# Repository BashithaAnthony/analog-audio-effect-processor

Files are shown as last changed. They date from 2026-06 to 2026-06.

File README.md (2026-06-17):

# Analog Audio Effect Processor

## Overview

Fully analog audio processing unit incorporating multiple audio effects, equalization stages, and dedicated power supply circuitry for audio signal enhancement.

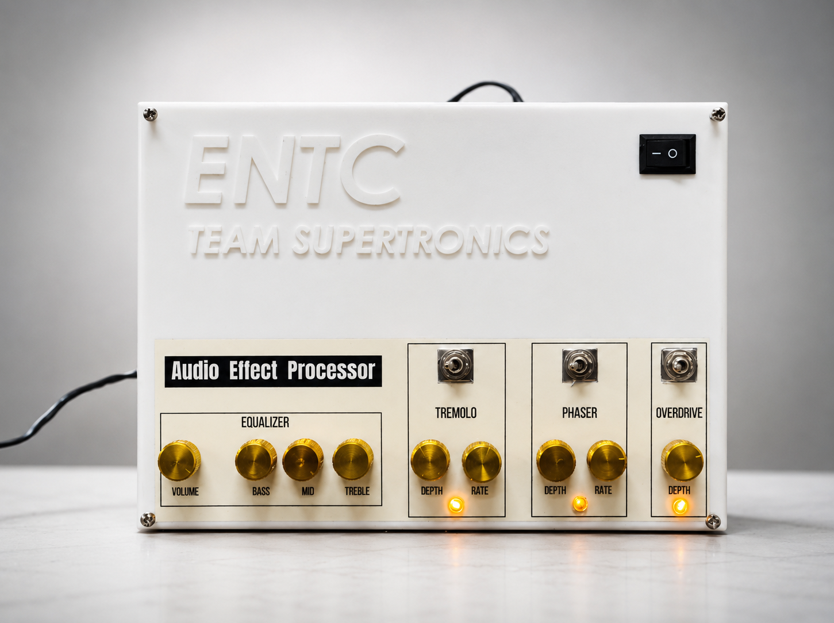
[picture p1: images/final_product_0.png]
Product Overview


## Features

* Equalizer section
* Tremolo effect
* Phaser effect
* Overdrive effect
* Analog signal processing
* Dedicated regulated power supply

## Technologies

* Analog Electronics
* LTSpice
* Altium Designer
* SolidWorks

## My Contributions

* Designed and simulated overdrive/distortion unit, input and output buffer circuits
* Developed the PCB using Altium
* Performed circuit analysis and validation
* Integrated multiple effect stages into a single system
* Designed initial sketches of enclosure and assisted in dinal enclosure designing

## Project Status

Completed

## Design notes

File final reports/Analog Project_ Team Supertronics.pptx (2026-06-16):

## EN2091 Analog Project

Team Supertronics

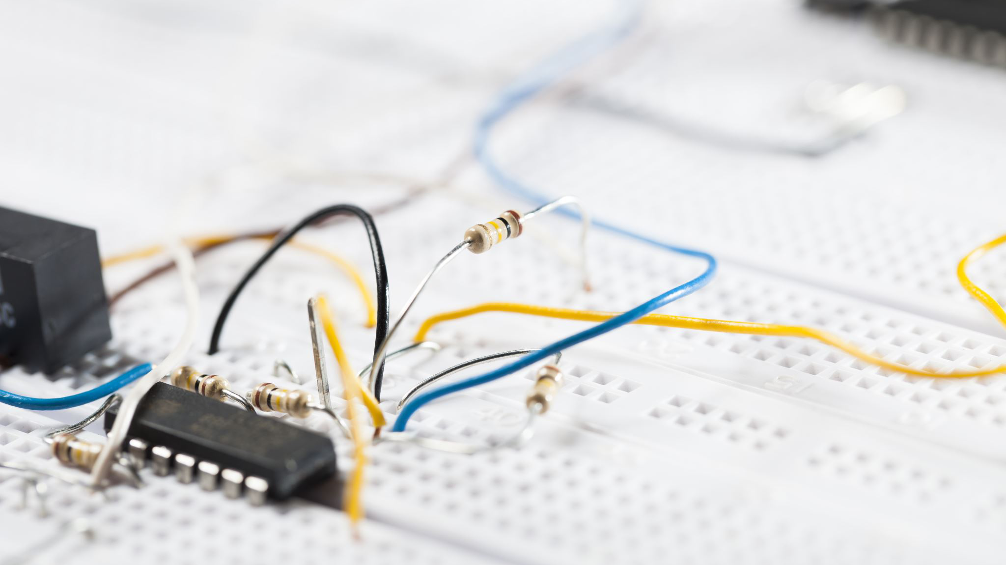
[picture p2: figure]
Electronics protoboard

230045X

230140J

230477X

230730T

Anthony C.S.B.

Dharmakeerthi P.K.G.C.L.

Perera H.A.J.I.

Wijethilaka J.S.

## Analog Audio Effect Processor

## Block Diagram

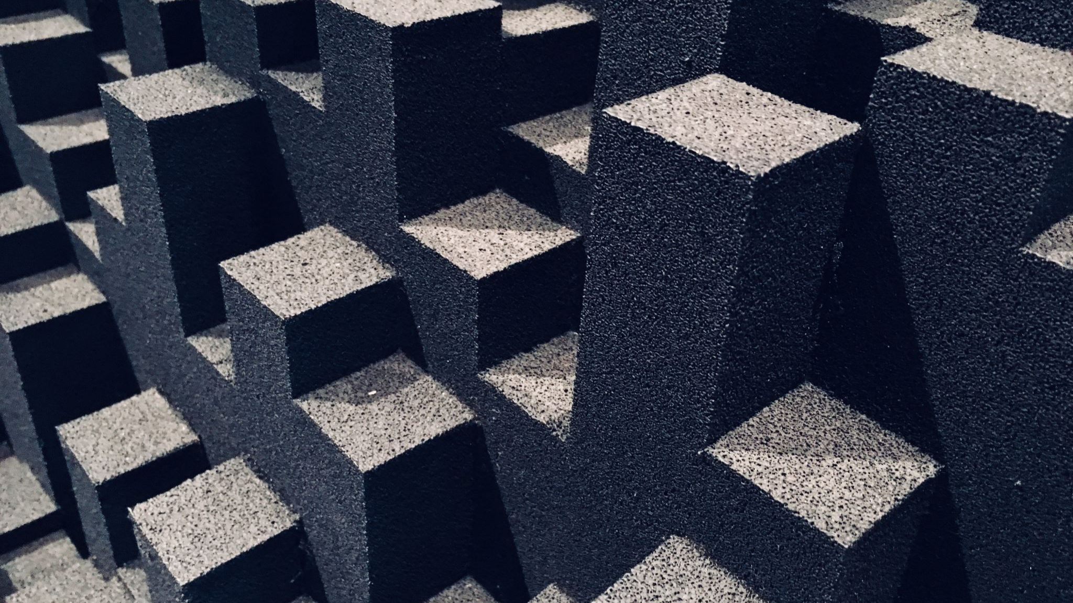
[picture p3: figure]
3D square and rectangle

Input Buffer

Equalizer

Tremolo

Overdrive

Phaser

Output Buffer

Regulated 12V Power Supply

## Power Supply

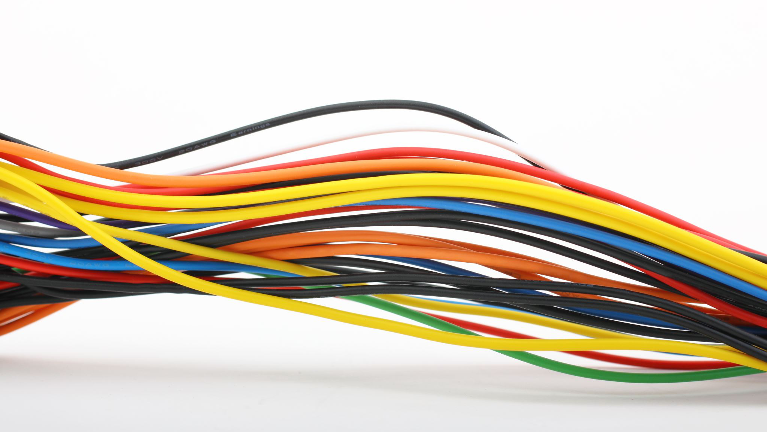
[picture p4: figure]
Colorful wires
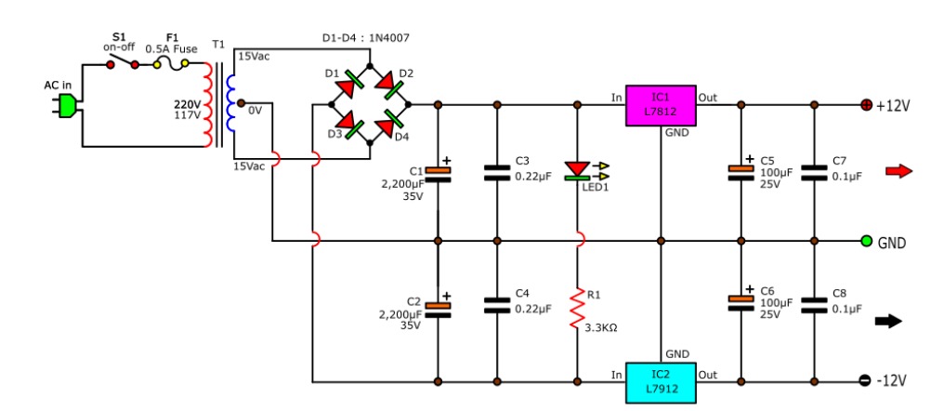
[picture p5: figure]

## 3-Band Audio Equalizer

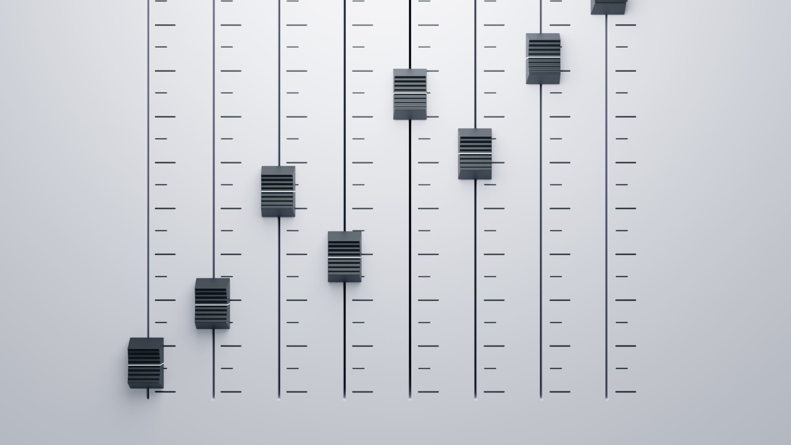
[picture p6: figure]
Volume sliders

## 3-Band Audio Equalizer

Introduction
- 3-band equalizer is an audio processing tool used to adjust the amplitude of different frequency bands in a sound signal.
- Commonly used in audio systems, music production, and live sound to shape the tonal quality of audio.
Functionality
- Allows boosting or cutting each frequency band independently and helps in improving clarity, warmth, and overall balance of audio.

## PCB Schematic (Audio Eq)

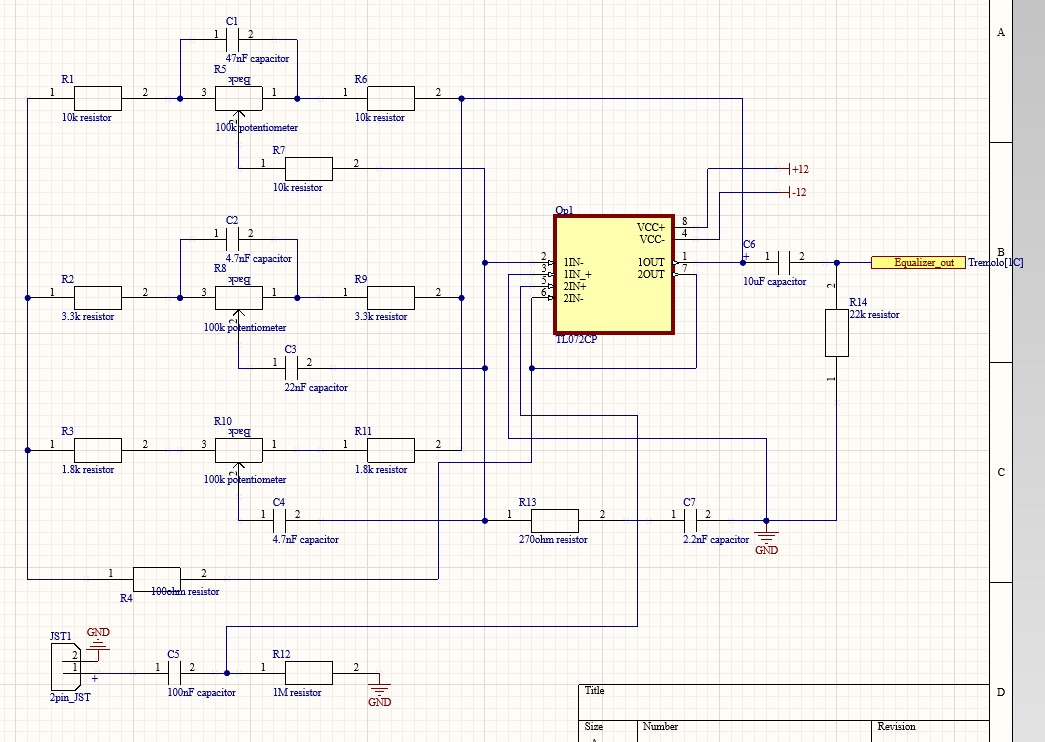
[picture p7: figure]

## Overdrive Module

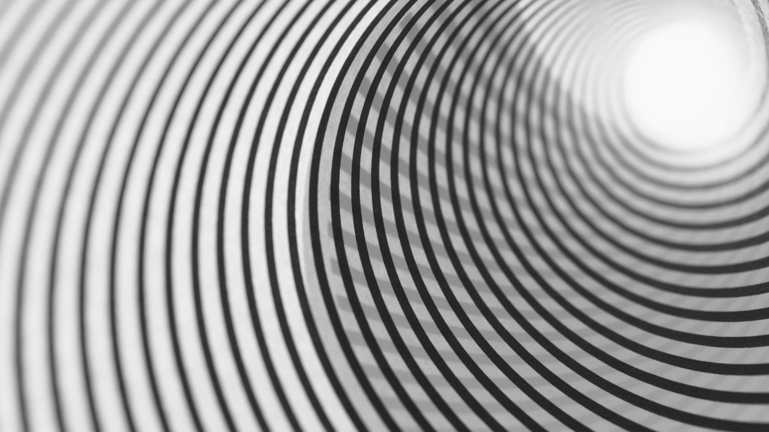
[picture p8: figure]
An illusion of swirling lines in black and white

## Overdrive Module

Introduction
- An Overdrive module is an audio effects unit that intentionally distorts the audio signal to produce a warm, saturated sound.
- Commonly used in electric guitars, synthesizers, and audio processing to add harmonic richness and character.
Functionality
- Boosts the signal and introduces harmonic distortion, making the sound more driven.
- Includes controls for Gain ( amount of distortion) and Volume (output signal strength ).

## PCB Schematic (Overdrive Module)

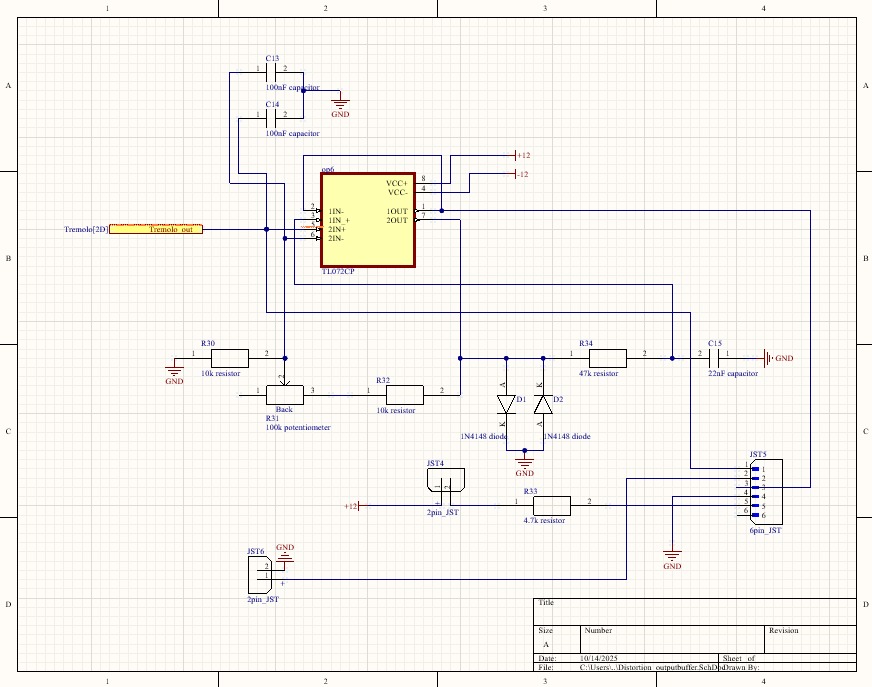
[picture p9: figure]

## Tremolo Module

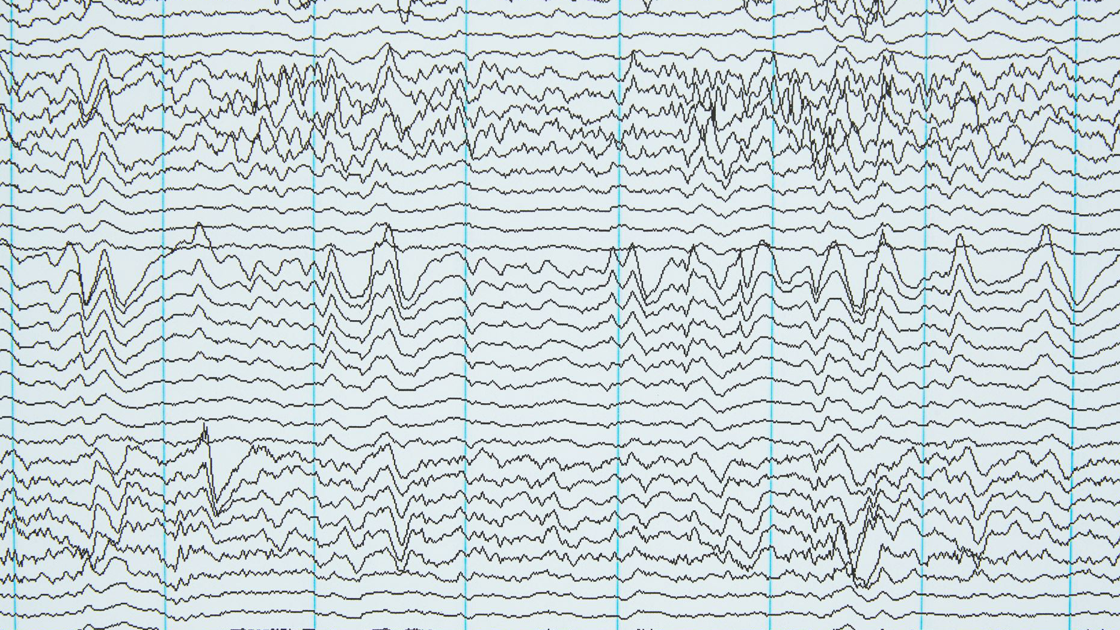
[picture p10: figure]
Zigzag indicator line

## Tremolo Module

Introduction
- A Tremolo module is an audio effect that modulates the amplitude (volume) of an audio signal periodically.
Functionality
- Modulates the amplitude of the input signal.
- Includes controls for Rate (speed of modulation) and Depth (intensity of the effect)

## PCB Schematic (Tremolo Module)

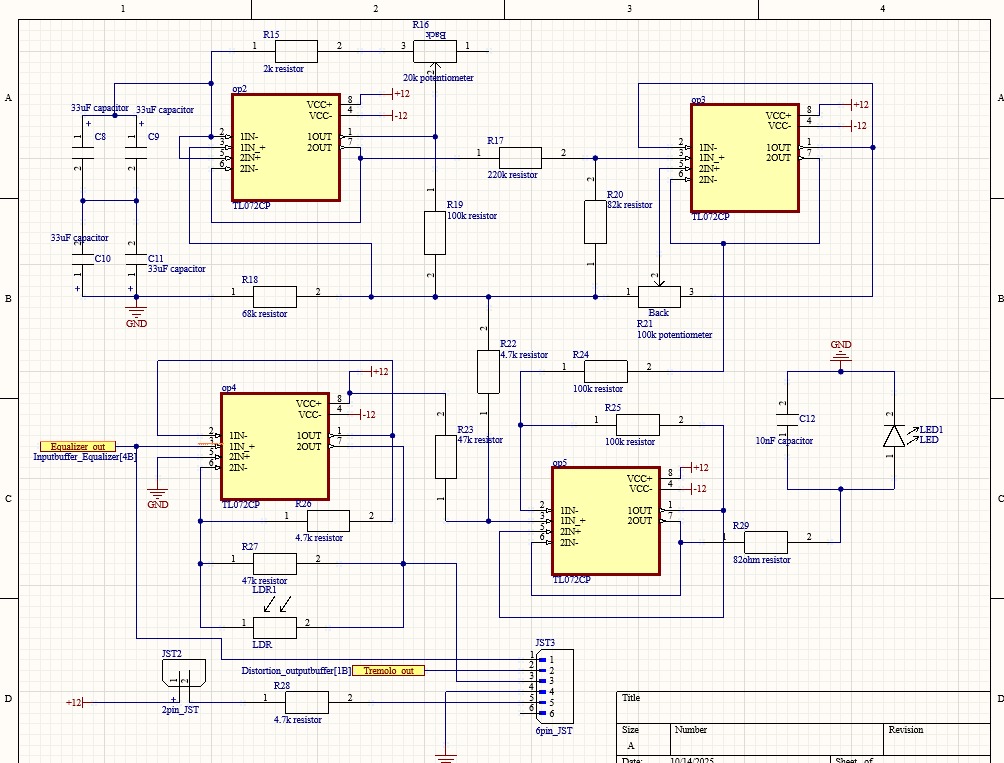
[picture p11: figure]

## Phaser Module

## Phaser Module

Introduction
- A Phaser module is an audio effect that creates sweeping, swirling sounds by splitting the audio signal and shifting the phase of one part before recombining.
Functionality
- Splits the input signal into two paths and shifts the phase of one path.
- Recombines the signals, causing constructive and destructive interference, producing peaks and troughs in the frequency spectrum.
- Includes controls such as Rate (speed of sweep) and Depth (intensity of effect)

## PCB Schematic (Phaser Module)

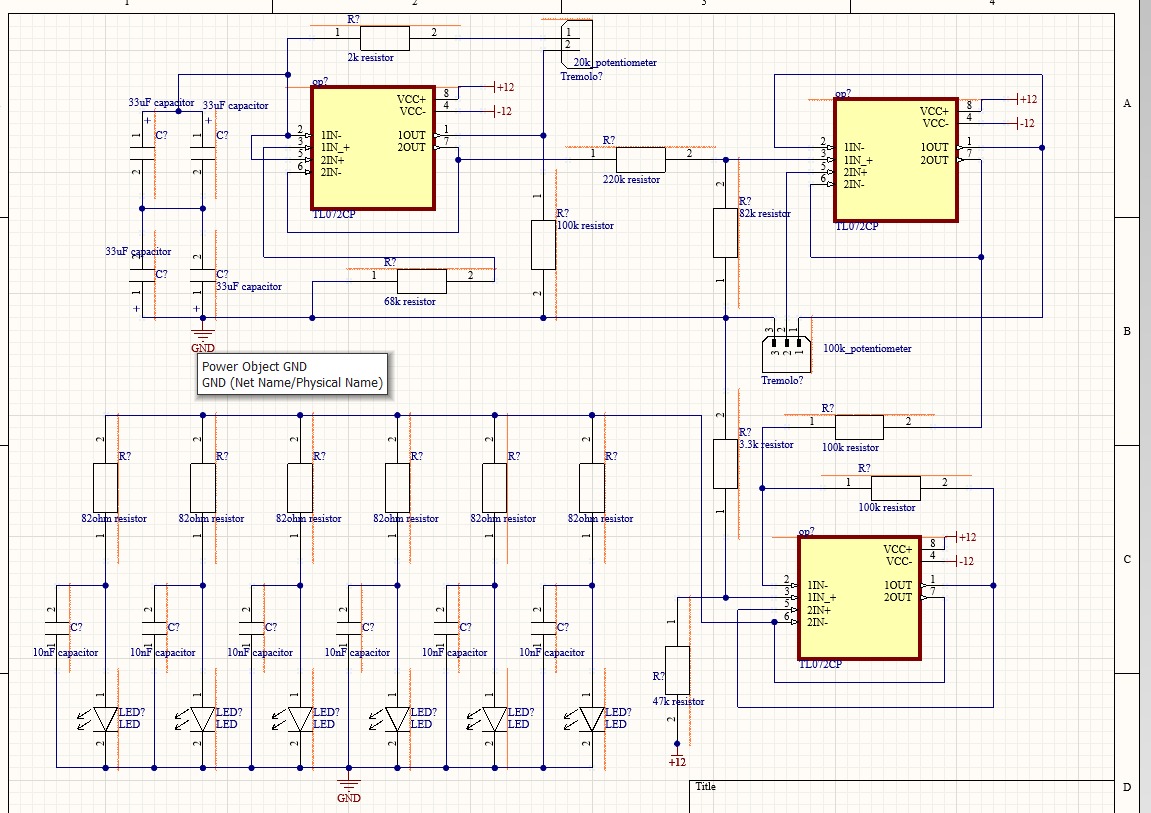
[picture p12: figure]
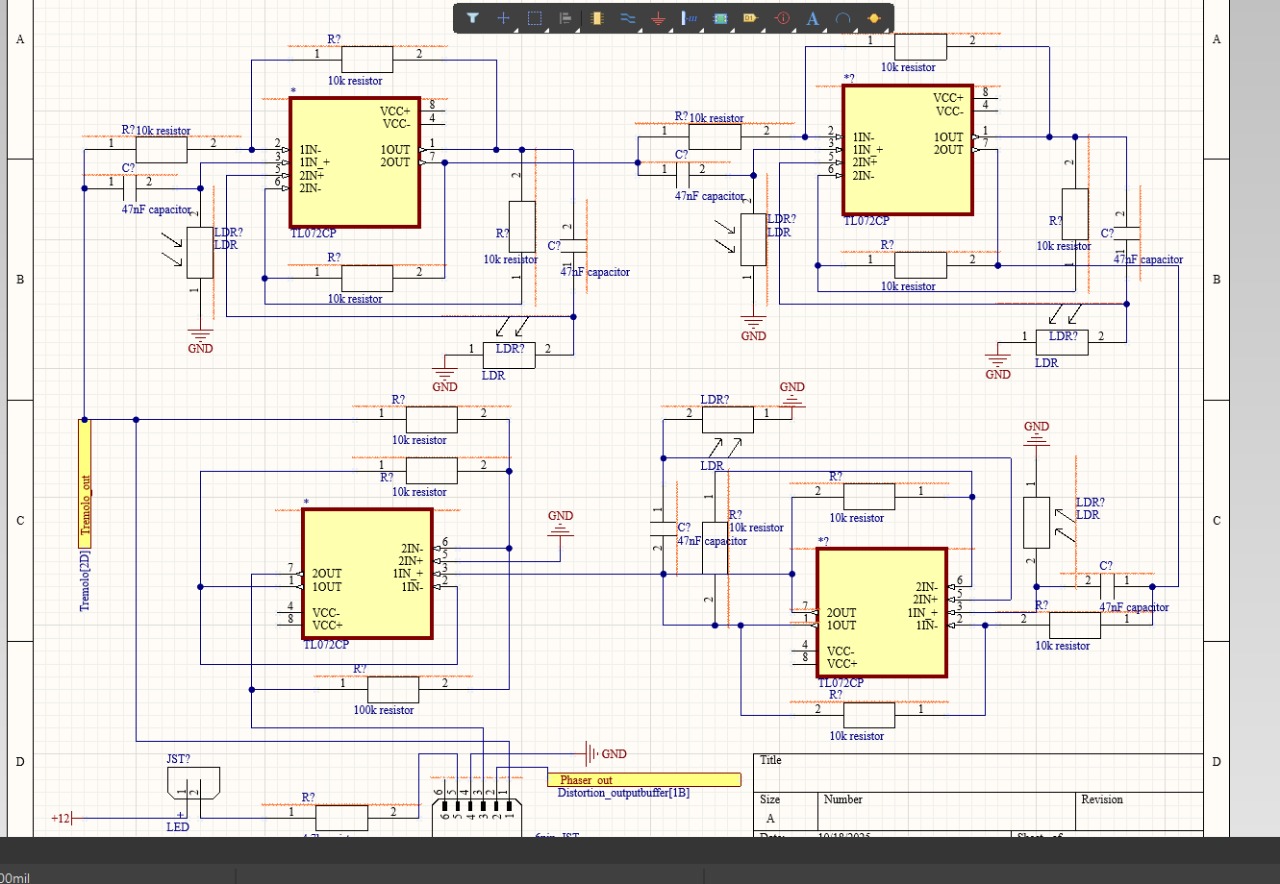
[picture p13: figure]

## PCB Layout

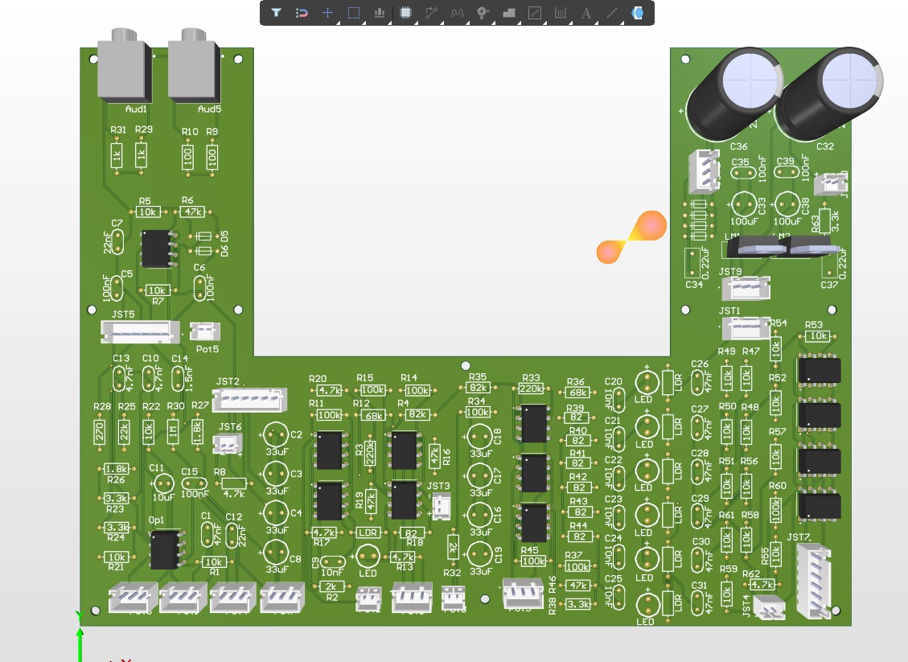
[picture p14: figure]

## Enclosure Design

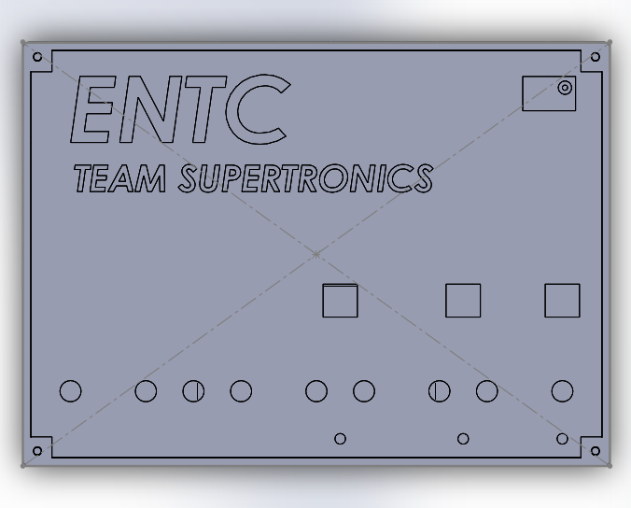
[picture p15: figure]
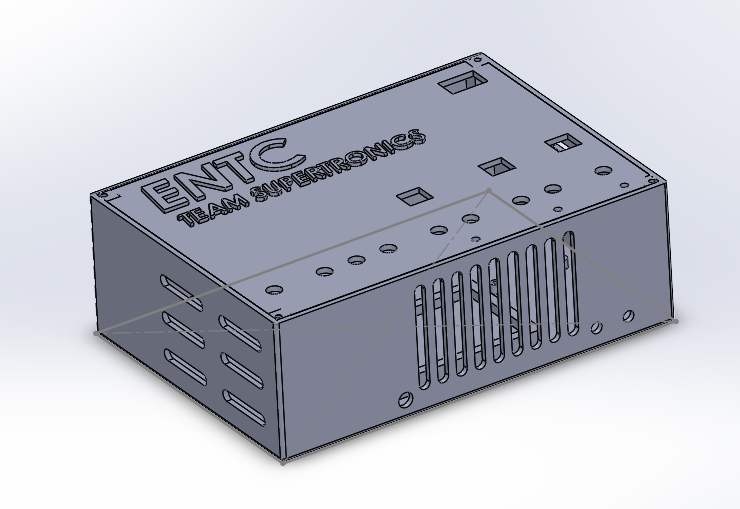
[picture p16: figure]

## Task Allocation

230045X | Overdrive Module, PCB Design
230140J | Phaser Module, Enclosure Design
230477X | Tremolo Module, Component Selection, Assembling
230730T | Audio Equalizer, Power Supply

## Thank You

Team SuperTronics

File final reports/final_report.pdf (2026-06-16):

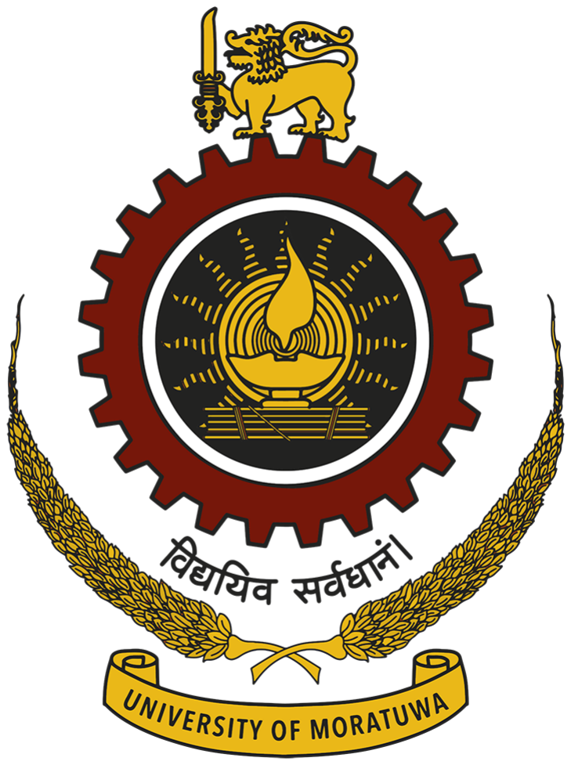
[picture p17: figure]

Department of Electronic & Telecommunication Engineering University of Moratuwa
Sri Lanka.

# Analog Audio Effects Processor

Group Name : Team SuperTronics

Group Members :

230045X | Anthony C.S.B
230140J | Dharmakeerthi P.K.G.C.L
230477X | Perera H.A.J.I
230730T | Wijethilaka J.S.

Submitted in partial fulfillment of the requirements for the module EN 2091 Laboratory Practice and Projects

Date : 14-12-2025

Analog Audio Effects Processor | Group No: 27

Abstract

This project presents the design and implementation of an analog audio effects processor which combines multiple commonly used audio effect into a single modular platform. The modules present in the project includes a power supply module capable of delivering a +-12V dual rail linear power supply, an input buffer, a three band audio equalizer, three audio effects namely as tremolo, phaser and distortion and an output buffer. The dual rail linear power supply is employed to ensure stable and low noise operation of the analog circuitry.

Each functional module is implemented using operational amplifier based circuits with careful attention given to impedance matching, maintaining signal integrity, noise reduction and maintaining proper gain control. Modulation effects such as tremolo and phaser are realized using low frequency oscillators and optical control elements (optocouplers) to achieve smooth and musically present variations. The distortion stage employs diode based clipping to introduce controlled non linearities suitable to achieve the desired effect.

The system was designed simulated and tested using industry standard software. Experimental results demonstrated that the processor successfully produced the intended audio effects while maintaining stable operation and acceptable signal quality. This project provides practical insight into analog audio circuit design and highlights the effectiveness of modular architecture in multi effect systems.

1

## Abbreviations and Acronyms

AC | Alternating Current
DC | Direct Current
LFO | Low Frequency Oscillator
EQ | Equalizer
PCB | Printed Circuit Board
LED | Light Emitting Diode
LDR | Light Dependent Resistor
IC | Integrated Circuit
RC | Resistor–Capacitor
PSU | Power Supply Unit
VCA | Voltage Controlled Amplifier

2

## Contents

1 Introduction and Functionality | 4
2 System Architecture | 4
3 Component Selection | 6
4 PCB Design | 7
5 Enclosure Design | 8
6 Software Simulation and Hardware Testing | 9
7 Conclusion & Future Works | 11
8 Contribution of Group Members | 11

3

## 1 Introduction and Functionality

Audio Effects play a vital role in audio signal processing by modifying the tonal, temporal and harmonic characteristics of the input audio signal. While modern digital signal processing techniques are widely used, analog audio effects remain popular due to their natural sound quality, continuous time operation and musical responce. designing analog audio effects also provides strong strong educational value as it requires a sound understanding of operational amplifiers, passive components and signal conditioning techniques.
The objective of this project is to design and implement an analog audio effects processor capable of processing a audio input signal through several commonly used audio effects. The system is intended to demonstrate practical applications of analog electronics concepts such as amplification, filtering, modulation and non linear signal processing.
The developed system consists of several modular stages each performing a specific function. An input buffer is used to match the impedance between the guitar pickup and the processing circuitry. A three band equalizer provides frequency shaping through bass, mid and treble controls. Modulation based effects such as tremolo and phaser are implemented using LFOs and optical control elements. A distortion stage introduces controlled non linear clipping to produce overdrive effects. Finally an output buffer ensures stable signal delivery to external audio output equipment.
The overall system accepts audio input through a 3.5mm audio input, processes it through the selected effects while preserving signal integrity and produces a clean, low noise audio output.

## 2 System Architecture

The audio effects processor is designed using a modular system architecture where each functional block operates independently while remaining electrically compatible with the rest of the system. This approach simplifies design, testing, debugging and future expansion. The system is powered by a centralized dual rail power supply that provides ±12 V to all analog stages.
The signal flow begins at the audio input jack where the incoming audio signal is first passed through an input buffer. This buffer provides high input impedance and prevents signal loading. The buffered signal is then routed through the equalizer stage, allowing tonal adjustment before modulation effects are applied. The processed signal subsequently passes through the tremolo and phaser stages where time varying modulation effects are introduced. A distortion stage follows, adding harmonic content through diode-based clipping. Finally, an output buffer delivers the processed signal to the output jack with low output impedance.
Careful attention has been given to inter module interfacing. AC coupling capacitors are used between stages to block DC offsets, while buffer amplifiers prevent impedance mismatches. Local decoupling capacitors are placed near op-amp power pins to minimize noise and ensure stable

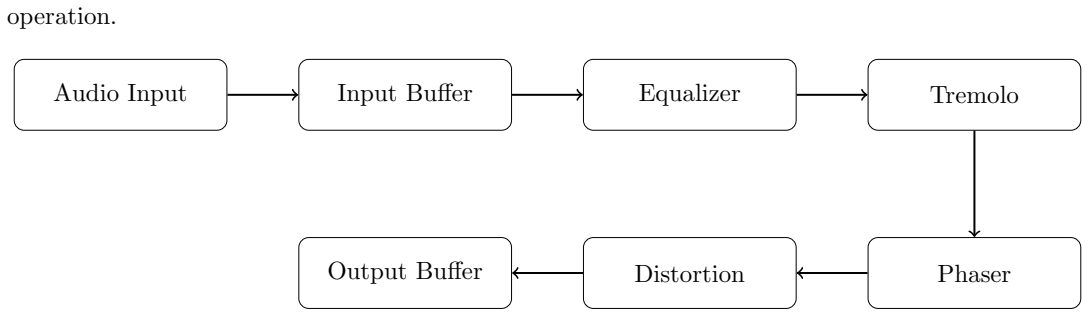
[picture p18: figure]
operation.; Audio Input; Input Buffer; Equalizer; Tremolo; Output Buffer; Distortion; Phaser

Figure 1: System architecture of the analog multi-effects audio processor

4

### 2.1 Table and Figure

Figures and tables are used in this report to clearly illustrate the structure and functionality of the proposed analog audio effects processor. Figure 1 presents the overall block diagram of the system, highlighting the modular signal flow from the audio input stage to the output buffer. The diagram demonstrates the sequential arrangement of the input buffer, equalizer, modulation effects, distortion stage and output buffer.
Table 1 summarizes the main functional modules of the system along with their respective functions and key components used in each module. The table provides a concise overview of the system organization and aids in understanding the role of each block within the complete audio processing chain.

Table 1: Functional modules of the audio effects processor

Module | Function | Key Components
Input Buffer | Impedance matching | TL072 op-amp
Equalizer | Frequency shaping | Op-amps, RC networks
Tremolo | Amplitude modulation | LFO, LED–LDR
Phaser | Phase modulation | LFO, LED–LDR
Distortion | Non-linear clipping | Diodes, op-amp
Output Buffer | Signal driving | TL072 op-amp

### 2.2 Equations

The operation of the proposed analog audio effects processor can be explained using a set of fundamental equations related to amplification, filtering and modulation. These equations describe the behavior of key circuit blocks implemented in the system.
The voltage gain of the operational amplifier stages used in the input buffer, equalizer, distortion and output buffer modules is determined using the standard non-inverting amplifier gain expression given by

Av = 1 +

Rf

Rin

, | (1)

where Rf represents the feedback resistance and Rin denotes the input resistance.

Frequency-selective behavior in the equalizer and filtering stages is characterized by the RC cutoff frequency, which is given by

fc =

1
2πRC , | (2)

where R and C are the resistance and capacitance values of the respective filter network.

The tremolo effect is based on the principle of amplitude modulation, in which the amplitude of the audio signal is varied by a low-frequency control signal. This behavior can be represented as

y(t) = x(t) [1 + m sin(2πfLF Ot)], | (3)

where x(t) is the input audio signal, m is the modulation depth, and fLF O is the frequency of the low frequency oscillator.

All equations are used to guide the design and analysis of the corresponding circuit blocks and support the functional behavior of the implemented audio effects.

5

### 2.3 Guidelines for References

The reference list is included in the References section at the end of this document. Sources are cited within the text using numbered references enclosed in square brackets. Each reference number corresponds to an entry in the reference list and appears in the order of first citation.
The references used in this project include textbooks on analog electronics and audio circuit design, as well as manufacturer datasheets for the components employed in the system.

## 3 Component Selection

Component selection was carried out with careful consideration of audio performance, reliability, availability, and suitability for analog signal processing. The selected components ensure stable operation, low noise, and effective realization of the intended audio effects.

- Operational Amplifier (TL072): The TL072 operational amplifier was chosen for the majority of signal processing stages including the input buffer, equalizer, distortion, tremolo, phaser and output buffer. This device features low input noise, JFET input transistors providing high input impedance and a wide bandwidth with a high slew rate suitable for audio based applications. The dual op-amp configuration also reduces component count and simplifies circuit implementation.
- Voltage Regulators (LM7812 and LM7912): The dual-rail power supply was implemented using LM7812 and LM7912 voltage regulators to provide regulated ±12 V DC outputs. These linear regulators were selected due to their reliability and low output ripple, which are important characteristics for analog audio circuits.
- Rectification and Filtering Components: Bridge rectification was achieved using 1N4007 diodes, selected for their high reverse voltage rating and suitability for low frequency rectification. Electrolytic capacitors were used for bulk smoothing of the rectified voltage, while ceramic capacitors were employed for high-frequency decoupling to improve power supply stability.
- Resistors and Capacitors: Resistors and capacitors were selected to form gain-setting, biasing, and frequency selective networks throughout the system. RC networks were designed to operate within the audible frequency range and to ensure stable and predictable circuit behavior.
- Potentiometers: Potentiometers were incorporated in the equalizer, tremolo, phaser and distortion stages to provide user adjustable control over gain, frequency, modulation rate and modulation depth. These components were selected to allow precise adjustment of circuit parameters ensuring that the required frequency response and gain characteristics could be achieved under varying operating conditions.
- Optical Components (LEDs and LDRs): Light-emitting diodes (LEDs) and light-dependent resistors (LDRs) were used in the tremolo and phaser modules to implement optical modulation. This approach helps achieve simple and smooth modulation of the audio signal.
- Diodes for Distortion (1N4148): Silicon signal diodes (1N4148) were employed in the distortion stage to introduce controlled non linear clipping. These diodes were selected due to their fast switching characteristics and consistent forward voltage which enable predictable and repeatable distortion behavior suitable for audio applications.

6

## 4 PCB Design

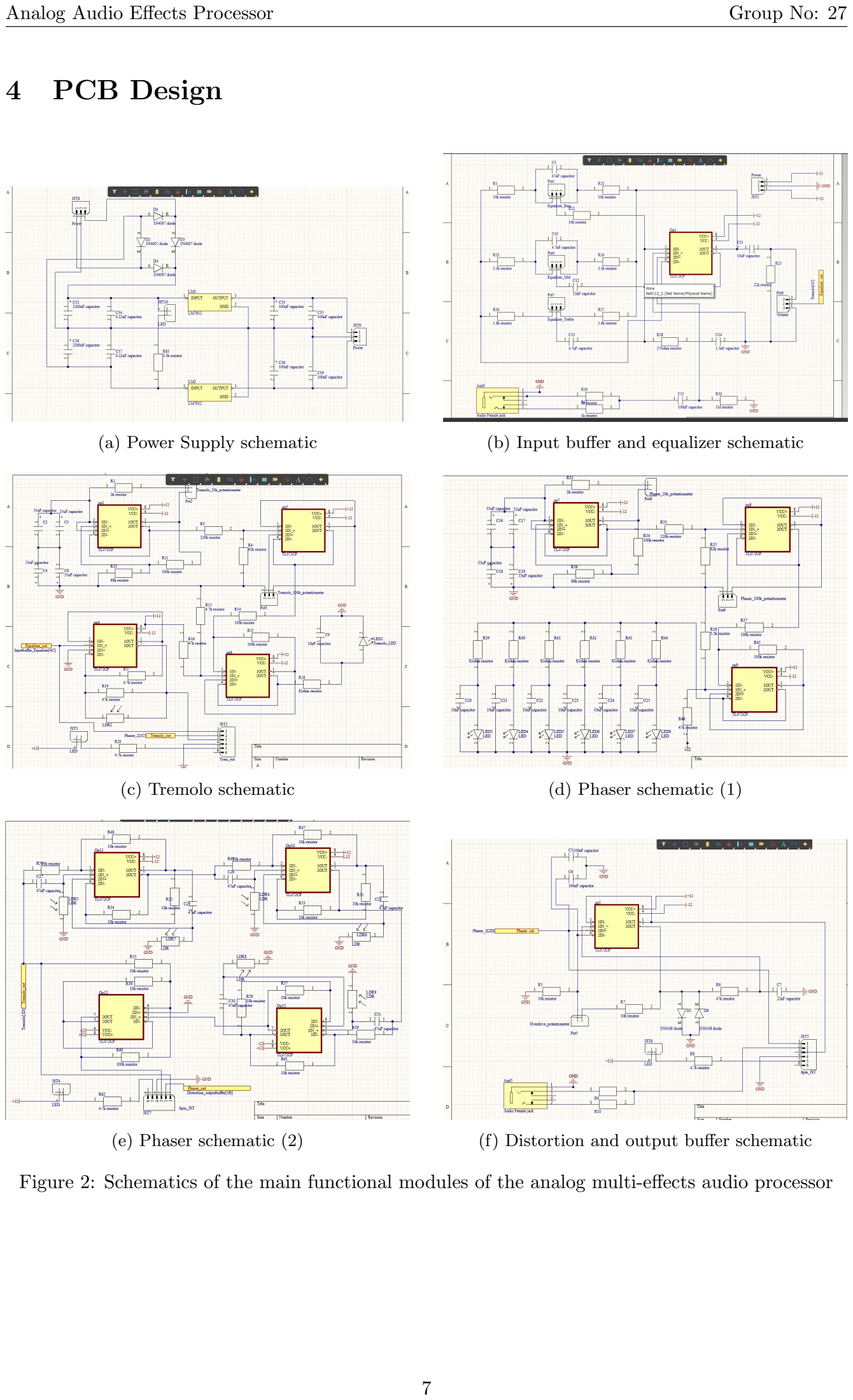
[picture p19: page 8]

(a) Power Supply schematic | (b) Input buffer and equalizer schematic
(c) Tremolo schematic | (d) Phaser schematic (1)
(e) Phaser schematic (2) | (f) Distortion and output buffer schematic

Figure 2: Schematics of the main functional modules of the analog multi-effects audio processor

7

## 5 Enclosure Design

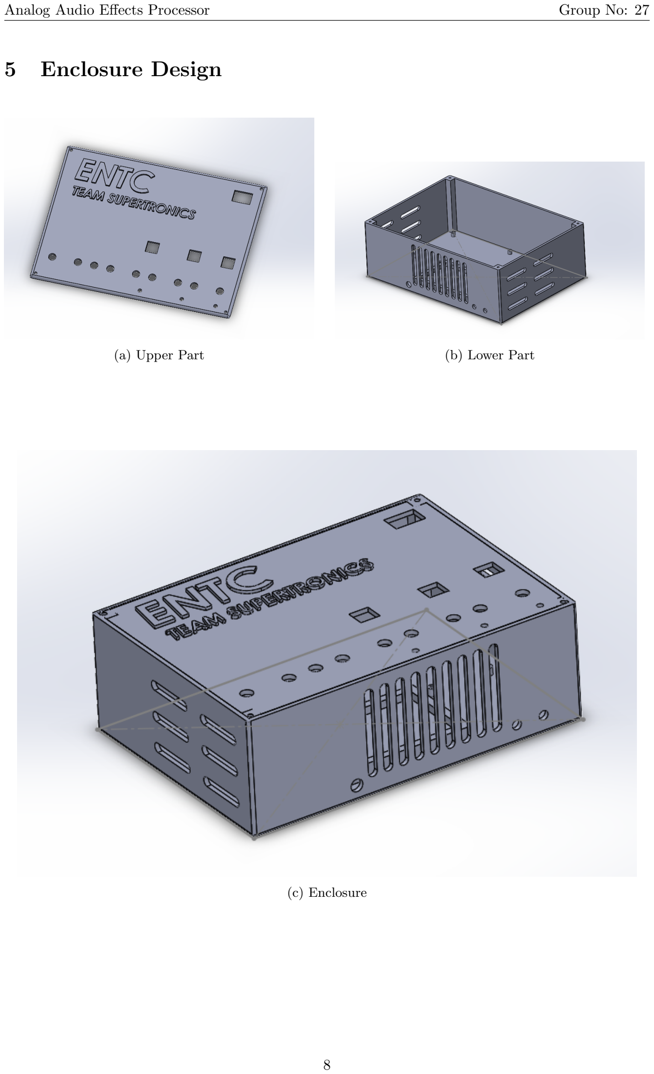
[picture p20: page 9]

(a) Upper Part | (b) Lower Part
(c) Enclosure

8

## 6 Software Simulation and Hardware Testing

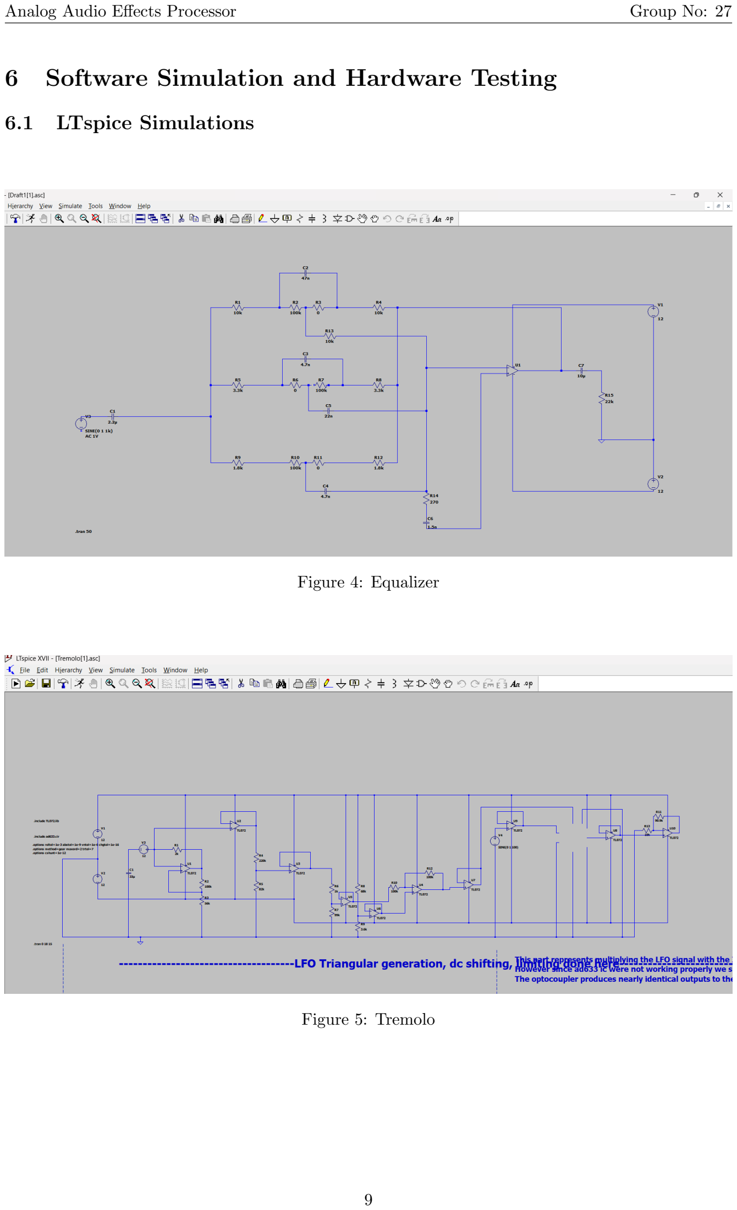
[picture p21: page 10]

### 6.1 LTspice Simulations

Figure 4: Equalizer

Figure 5: Tremolo

9

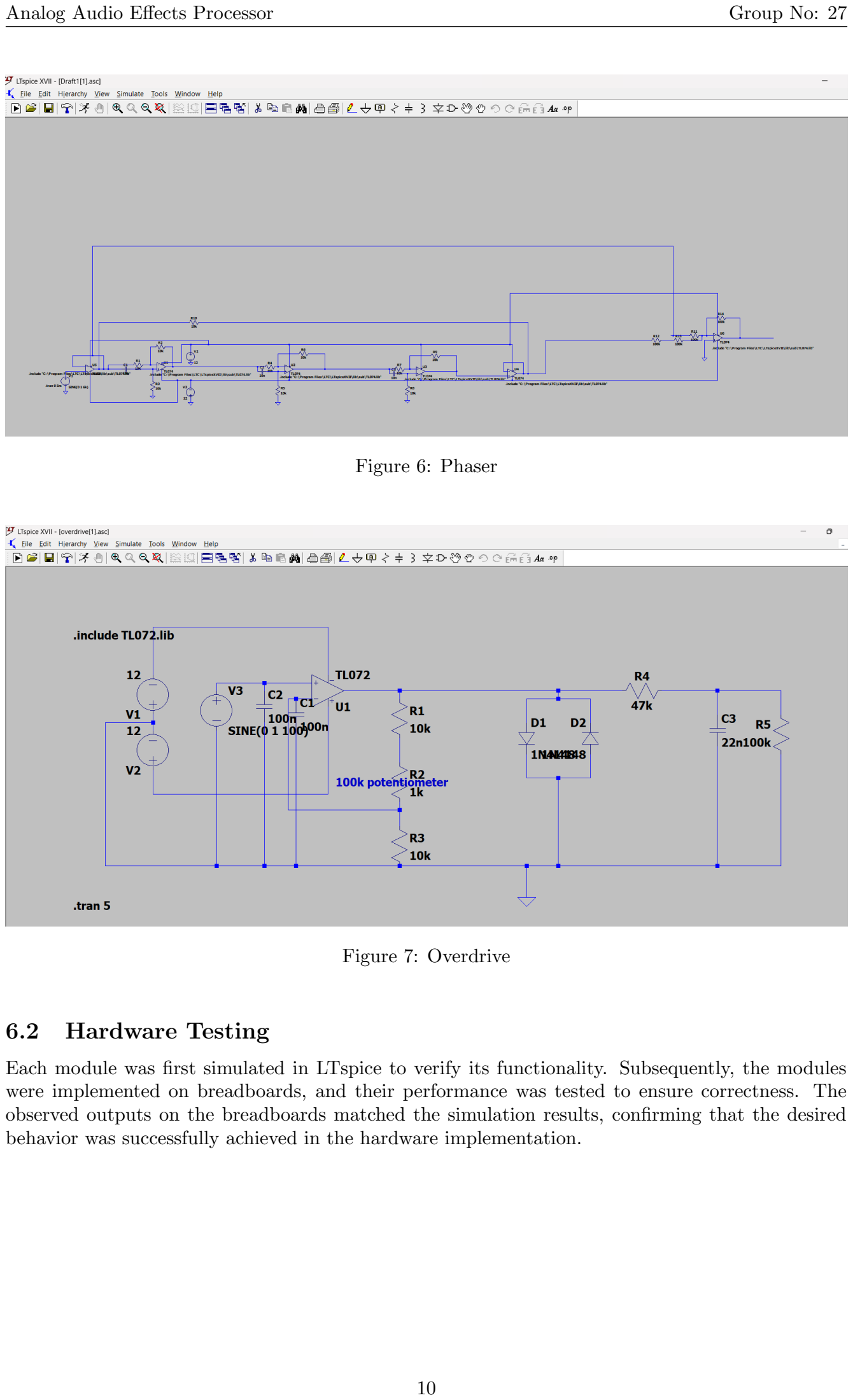
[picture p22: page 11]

Figure 6: Phaser

Figure 7: Overdrive

### 6.2 Hardware Testing

Each module was first simulated in LTspice to verify its functionality. Subsequently, the modules were implemented on breadboards, and their performance was tested to ensure correctness. The observed outputs on the breadboards matched the simulation results, confirming that the desired behavior was successfully achieved in the hardware implementation.

10

## 7 Conclusion & Future Works

We successfully achieved the design and implementation of an analog audio effects processor intended for audio signal processing. The system integrates several commonly used audio effects including a three band equalizer, tremolo, phaser and distortion into a single modular platform powered by a dual-rail ±12 V supply. The modular architecture adopted in the design facilitated systematic development, testing, and integration of individual functional blocks.
Hardware testing confirmed stable operation of the power supply and reliable performance of all signal processing stages. Each effect module produced the intended audible characteristics while proper buffering and grounding ensured acceptable signal quality with acceptable noise. Through this project we gained valuable practical experience in operational amplifier based circuit design, analog signal processing, PCB layout considerations and system level integration of multiple electronic subsystems.
Several enhancements can be considered as future work to further improve the functionality and performance of the system. Digital control of effect parameters using a microcontroller could be introduced to enable preset storage and improved user interaction. Additional audio effects such as delay, chorus and reverb could be incorporated to expand the versatility of the processor.

## 8 Contribution of Group Members

Index | Tasks
230045X | Overdrive Module, PCB Design
230140J | Phaser Module, Enclosure Design
230477X | Tremolo Module, Component Selection, Assembling
230730T | Audio Equalizer, Power Supply

## Appendix

## References

[1] B. Cordell, Designing Audio Circuits and Systems, Taylor & Francis Ltd, 2024.
[2] J. C. M. Lam, Analog Audio Amplifier Design, Focal Press, 2024.

11

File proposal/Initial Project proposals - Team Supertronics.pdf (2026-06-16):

# Feasibility Report

## Analog Audio E!ect Processor

Group Members:
230045X, 230140J, 230477X, 230730T

## Functionality

The proposed Analog Audio E!ect Processor is a modular, fully analog device designed to apply multiple sound e!ects to an audio signal in real time. The system will feature four distinct audio e!ects as follows:

- Overdrive/Distortion – Adds harmonic saturation and controlled clipping for a warm or aggressive tone.
- Phaser – Produces sweeping, phase-shifted comb filter e!ects using multiple all-pass filter stages.
- Tremolo – Modulates the amplitude of the signal periodically for a pulsing e!ect.
- Spring Reverb – Simulates reverberation using a mechanical spring tank.

Each module will be independently switchable, allowing the user to activate any combination of e!ects as the user wants. The signal will be processed in series for a straightforward and compact design.

## Block Diagram of the System

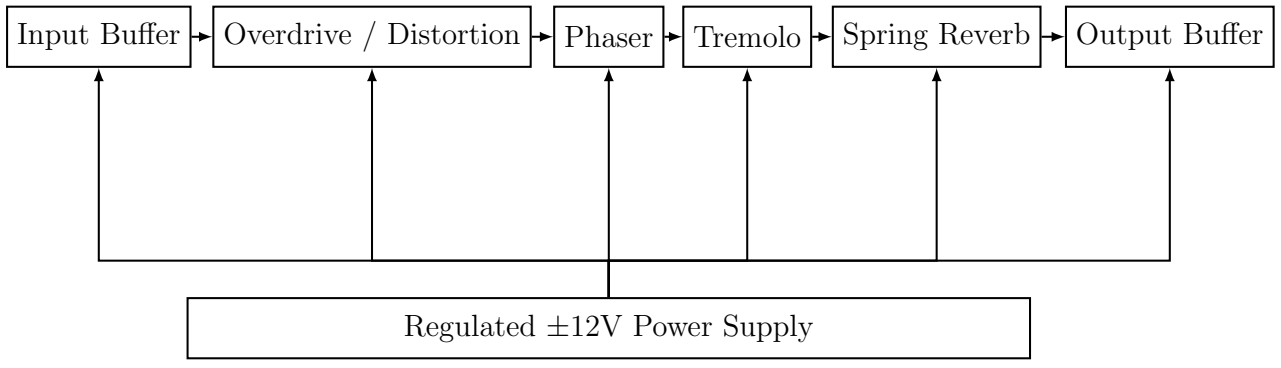
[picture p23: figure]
Input Bu!er; Overdrive / Distortion; Phaser; Tremolo; Spring Reverb; Output Bu!er; Regulated ±12V Power Supply

## Methodology

The development process is going to be carried out in the following stages:

1. Research and Analysis: Review existing analog e!ect circuits, studying their topologies, performance characteristics, and integration requirements. Identify component types suitable for low-noise, high-fidelity audio.
2. Design Stage:
- Draw schematics for each e!ect module (Overdrive, Phaser, Tremolo, Spring Reverb) using professional software.
- Incorporate bu!ers at the input and output of each e!ect for impedance matching.
- Include individual bypass switching systems for each e!ect to allow any combination of active modules.
3. Simulation: Model each circuit in LTspice to verify frequency response, distortion levels, and modulation behavior before prototyping.
4. Prototyping:
- Build each module separately on a breadboard.
- Test each module’s sound quality, noise level, and switching performance.
5. Integration: Interconnect modules in series on a unified breadboard prototype. Check that bypass switching works without pops or signal degradation.
6. PCB Design: Design the final PCB with careful grounding and power decoupling to minimize interference. Ensure physical layout accommodates control knobs and switches.
7. Enclosure Design: Create a SolidWorks 3D model for the enclosure, considering mechanical mounting for the spring reverb tank and ergonomic placement of controls.
8. Assembly and Testing: Assemble all modules on the PCB, install into the enclosure, and perform full system audio tests under di!erent e!ect combinations.

## Micro-products and Interconnections

The system consists of four main e!ect modules and supporting circuits:

- Overdrive Module – Op-amp gain stage with diode clipping and tone control.
- Phaser Module – Multi-stage all-pass filters with LFO-controlled JFETs or OTAs.
- Tremolo Module – LFO-driven voltage-controlled amplifier.

- Spring Reverb Module – Mechanical reverb tank with preamp and recovery stage.
- Bu!ers and Power Supply – Op-amp bu!ers and regulated dual-rail supply.
- Switching System – Bu!ered bypass or latching relays for each module.

Modules are interconnected using analog audio paths on PCB traces, with shared power rails and star-grounding to reduce noise.

## Micro-product Allocation Among Group Members

Index Number | Allocated Tasks
230045X 230140J 230477X 230730T | Overdrive module, input bu!er, PCB designing Phaser module, switching, enclosure designing Tremolo module, output bu!er Spring reverb module, power supply

## References

1. Hunter, D., Guitar E!ects Pedals: The Practical Handbook. Backbeat Books, 2004.
2. Horowitz, P., Hill, W., The Art of Electronics, 3rd ed. Cambridge University Press, 2015.
3. Small, R., Op Amp Applications Handbook. Newnes, 2005.
4. Accutronics, Spring Reverb Tank Datasheets, 2020.

# Voice-Controlled LED Light Show

## Team SuperTronics

230045X - Anthony C.S.B.
230140J - Dharmakeerthi P.K.G.C.L. 230477X - Perera H.A.J.I.
230730T - Wijethilaka J.S.

## Functionality

The proposed system will create an LED light display that responds to the user’s voice or music in real-time. The system will capture audio signals through a microphone, process them using analog electronics (amplifiers, filters, and envelope detectors), and drive LED arrays accordingly. The brightness and pattern of the LEDs will change with the loudness and frequency components of the input audio. Optionally a microcontroller will be used to display e!ects and mode selection.

## Block Diagram

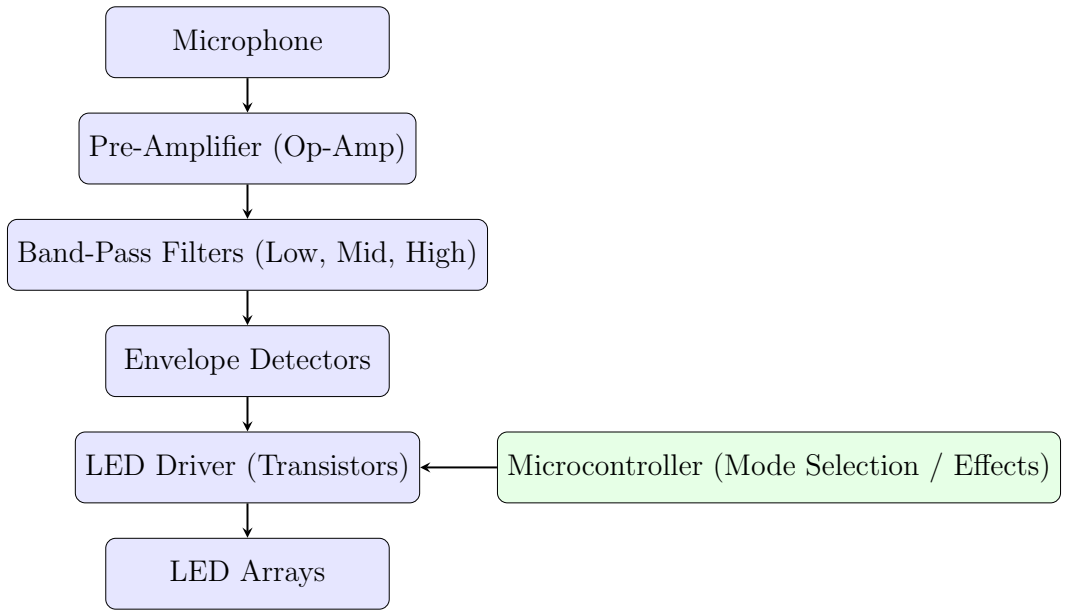
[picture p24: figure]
Microphone; Pre-Amplifier (Op-Amp); Band-Pass Filters (Low, Mid, High); Envelope Detectors; LED Driver (Transistors); LED Arrays; Microcontroller (Mode Selection / E!ects)

## Methodology

The development process will be carried out in the following stages:

1. Research and analysis. Review existing analog audio-responsive lighting circuits, studying their topologies, performance characteristics, and integration requirements. Identify component types suitable for low-noise amplification, accurate frequency filtering, and reliable LED driving.
2. Design stage.
- Draw schematics for each subsystem (Amplification, Filtering, Detection, LED Driving, Power Supply) using professional circuit design software ensuring proper impedance matching between stages to minimize signal loss
- Incorporate transistor-based or op-amp-based driver circuits capable of handling the required LED current.
3. Simulation. Model each circuit in LTspice to verify gain levels, filter frequency responses, envelope detection behavior, and LED driver performance before hardware implementation.
4. Prototyping.
- Build each subsystem separately on a breadboard.
- Test the performance of each subsystem individually checking noise levels, frequency separation, detection accuracy, and LED brightness control.
5. Integration. Interconnect all subsystems in sequence to form the complete system. Verify that the LED arrays respond in real-time to changes in audio input across di!erent frequency bands.
6. PCB design. Design the final PCB with proper grounding, signal routing, and decoupling to minimize interference between analog audio paths and high-current LED lines.
7. Enclosure design. Create a 3D model of the enclosure, ensuring secure mounting for the PCB, microphone, LEDs, and optional microcontroller interface, with attention to aesthetics.
8. Assembly and testing. Assemble all components into the pcb, connect the power supply, and tests with di!erent audio sources to verify responsiveness, stability, and lighting e!ects.

## Micro Products and Interconnections

1. Audio Capturing Module: A microphone will be used to capture the voice or music signal from the environment.
2. Signal Conditioning Module: The weak microphone signal will be amplified using a low-noise op-amp based preamplifier to bring it to a usable voltage level.
3. Frequency Band Separation Module: The amplified signal will be split into several distinct frequency ranges (low, mid, high) using analog band-pass filter circuits.
4. Amplitude Detection Module: Each filtered signal will pass through an envelope detector circuit to measure its amplitude, which corresponds to the loudness in that frequency range.
5. LED Driving Module: The detected amplitude signals will control transistor-based LED driver circuits. The brightness of each LED array will change dynamically according to the corresponding frequency band’s amplitude.
6. Optional Microcontroller Control: A microcontroller may be used to select di!erent LED display patterns or operating modes. The microcontroller will interface with the LED driver stage without replacing the analog processing path.
7. Power Supply Module: Provides regulated DC voltages required for the entire system. This includes a dedicated LED supply rail for the high-current LED arrays, and regulated low-voltage rails for the analog circuits and optional microcontroller.

End-to-end flow: Microphone → Amplification → Filtering → Detection → Output (LED arrays).

## Task Allocation

Subsystem / Task | Assigned Member
Audio capturing and Signal conditioning modules | 230045X
Frequency band seperation and optional microcontroller module | 230477X
Amplitude detection and Power supply modules | 230140J
LED driving and power supply modules | 230730T

## References

1. Texas Instruments, Single-Supply, Electret Microphone Pre-Amplifier Reference Design (TIDU765): https://www.ti.com/lit/ug/tidu765/tidu765.pdf
2. Elliott Sound Products, LED Lighting E!ects for Audio: https://sound-au.com/project60.htm

# Feasibility Report Analog Thermoelectric Cooling Controller

Group: Team SuperTronics
230045X - Anthony C.S.B.
230140J - Dharmakeeerthi P.K.G.C.L. 230477X - Perera H.A.J.I.
230730T - Wijethilaka J.S.

## Functionality

The proposed system will control the temperature of a 12 V, 6 A thermoelectric cooler (TEC) using a fully analog feedback loop. A proportional-integral (PI) control stage, implemented using op-amps and RC networks, will regulate the TEC current via a PWM power driver stage. The system will maintain a set temperature setpoint despite environmental changes. Current sensing and overcurrent protection will ensure safe operation. A microcontroller may optionally be used for displaying the setpoint and measured temperature, but the control and actuation path will remain purely analog.

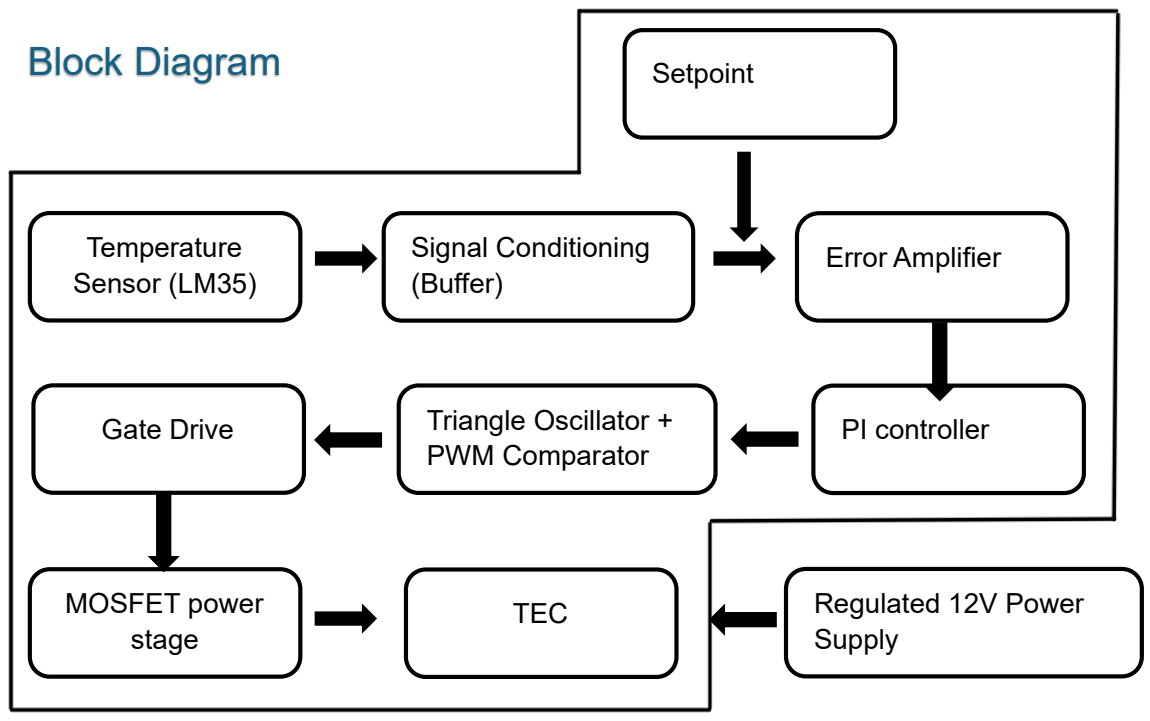
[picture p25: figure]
Block Diagram; Temperature Sensor (LM35); Signal Conditioning (Buffer); Setpoint; Error Amplifier; PI controller Triangle Oscillator + PWM Comparator; Gate Drive; MOSFET power stage; TEC; Regulated 12V Power; Supply

## Methodology

- Research and component selection: Study TEC operation, op-amp PI controllers, PWM generation, and MOSFET driver design.

- Circuit design: Draw schematics for sensing, PI control, PWM generation, MOSFET driver, and protection stages.
- Subsystem prototyping: Build and test each module individually on breadboards to verify

correct operation.
- Integration: Connect all modules in sequence and verify stable temperature regulation.
- Testing: Measure temperature stability, response to disturbances, and overcurrent protection function.
- Enclosure design: Prepare housing with heatsink and fan for hot side, ensuring safe mounting of components.
- Final assembly: Install all components, route wiring, and finalize the project for demonstration.

## Micro Products and Interconnections

- Temperature Sensor Module: LM35 sensor with op-amp conditioning outputting analog voltage to error amplifier.
- Setpoint Generator: Potentiometer with buffer stage providing reference voltage.
- Error Amplifier + PI Controller: Op-amp stages generating control voltage for PWM.
- Triangle Wave Oscillator: Op-amp integrator + comparator generating sawtooth/triangle waveform.
- PWM Comparator: Compares PI output to triangle wave, producing PWM signal.
- MOSFET Power Stage: Low-side driver switching TEC power line.
- Current Sense Module: Shunt resistor with op-amp amplifier to measure TEC current.
- Overcurrent Protection Module: Comparator output disabling PWM when threshold exceeded.
- Display Module: Microcontroller reads temperature and setpoint, displaying via I²C/SPI LCD.

## Micro-product Allocation Among Group Members

- Temperature sensing and setpoint generation,PCB design – 230045X
- Error amplifier and PI control design,enclosure design- 230140J
- PWM generation and triangle oscillator – 2300477X
- MOSFET power stage and current sensing – 230730T

1. Texas Instruments, 'LM35 Precision Centigrade Temperature Sensor Datasheet'.
2. Texas Instruments, 'LM358 Low Power Dual Op-Amp Datasheet'.
3. International Rectifier, 'IRLB3034 N-Channel MOSFET Datasheet'.
4. Horowitz, P., & Hill, W., 'The Art of Electronics', 3rd Edition.
5. Application notes on PWM current control for TEC modules.

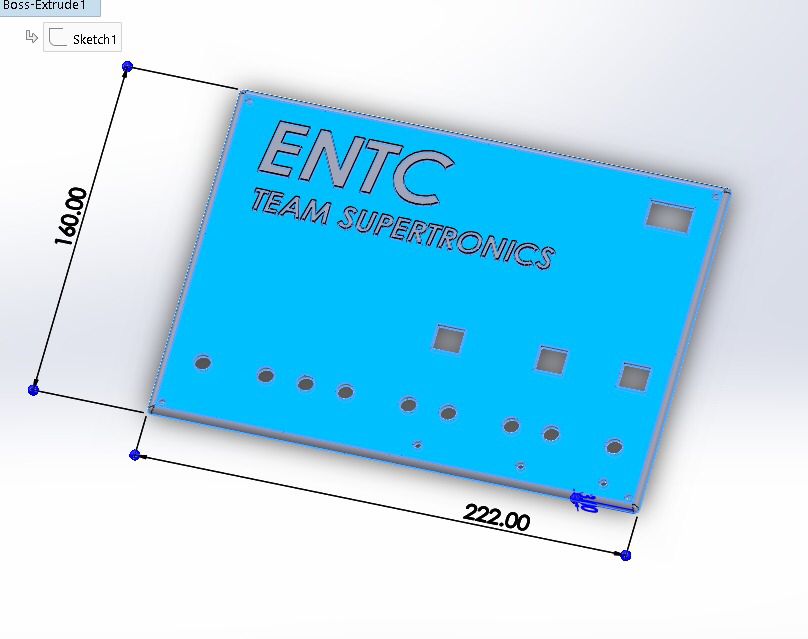
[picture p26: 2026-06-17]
design files/Enclosure_design/SolidWorkss_Design_1.jpeg

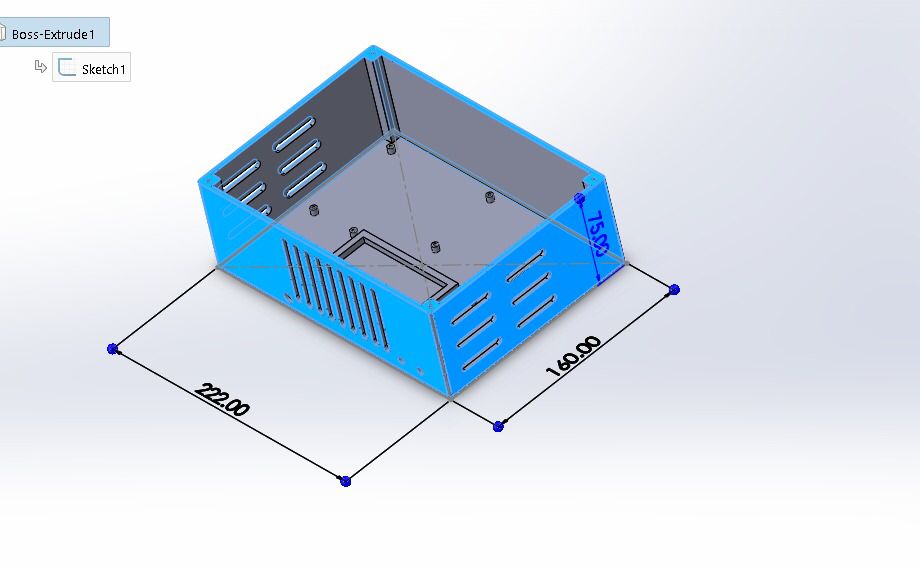
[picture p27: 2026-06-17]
design files/Enclosure_design/SolidWorkss_Design_0.jpeg

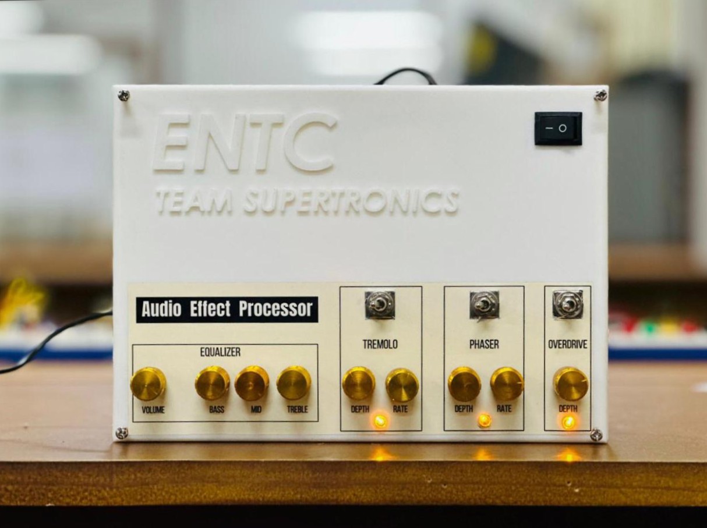
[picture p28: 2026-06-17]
images/final_product_1.jpeg

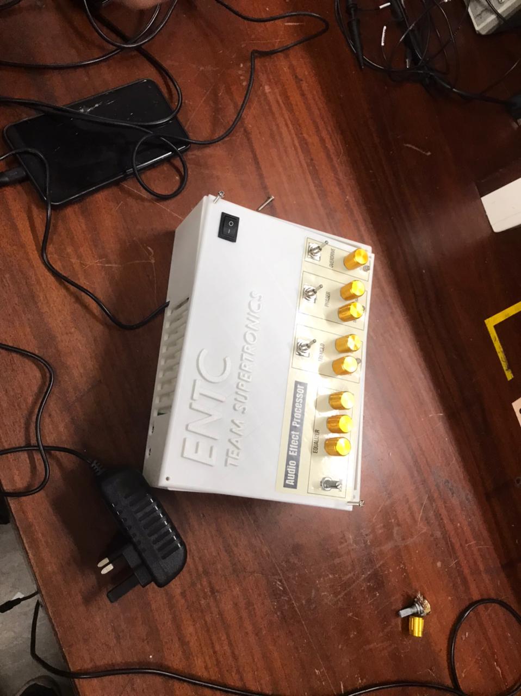
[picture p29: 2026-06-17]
images/final_product_2.jpeg

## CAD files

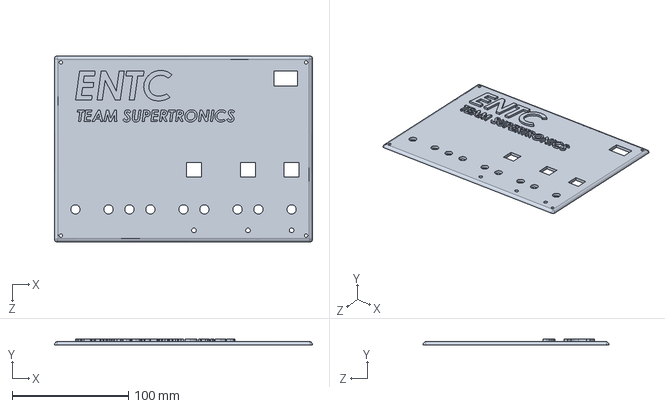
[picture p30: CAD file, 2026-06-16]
design files/Enclosure_design/Upper.SLDPRT
222.0 x 5.00 x 160.0 mm

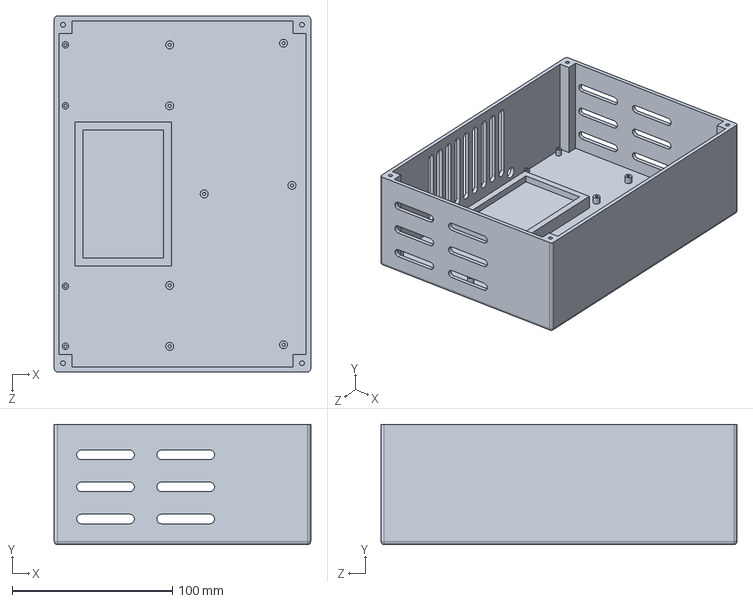
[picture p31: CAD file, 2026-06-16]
design files/Enclosure_design/Under.SLDPRT
160.0 x 75.0 x 222.0 mm

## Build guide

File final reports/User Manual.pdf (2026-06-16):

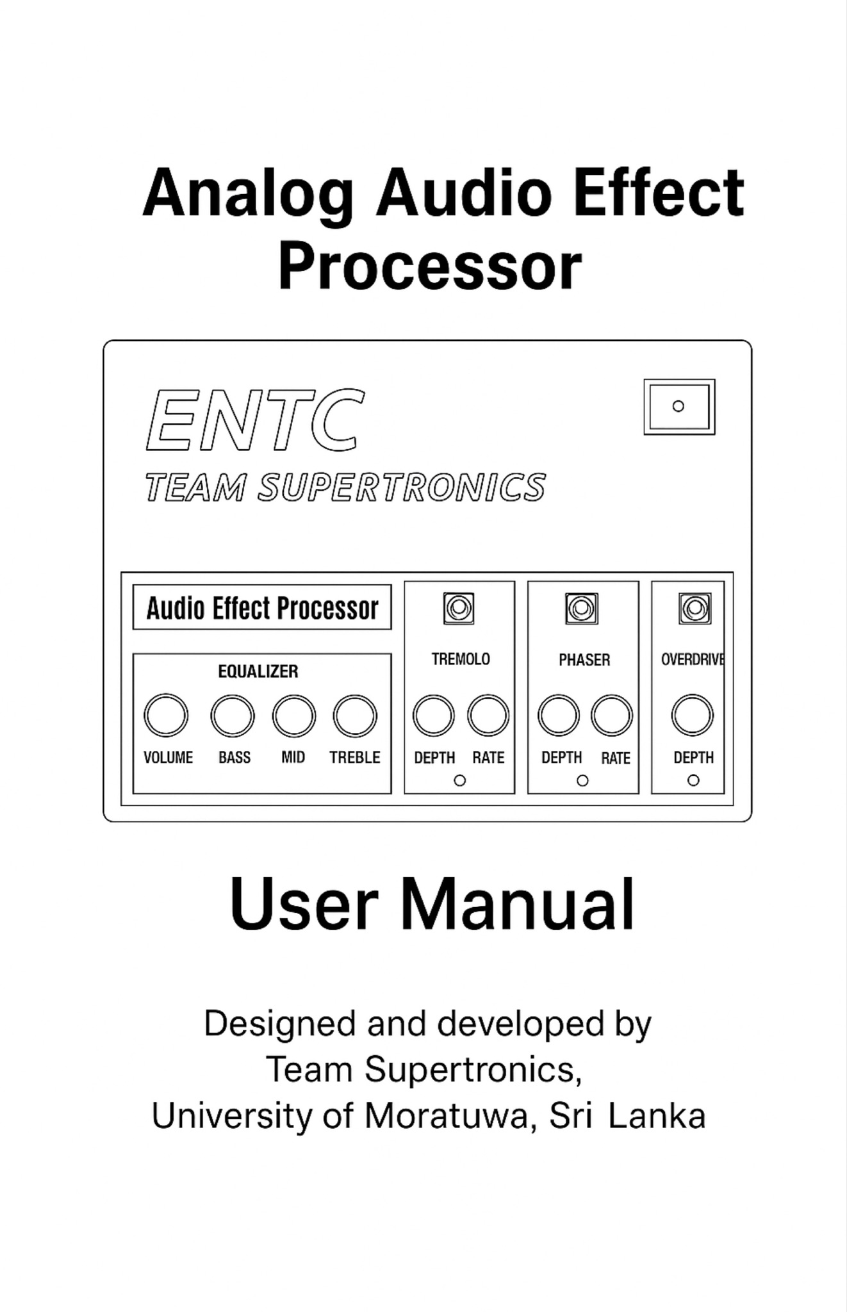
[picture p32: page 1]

### 1 Introduction

The Analog Audio Effect Processor is a fully analog signal-processing device designed for real-time audio manipulation. The system integrates multiple classic audio effects using operational amplifiers, passive components, and discrete analog circuitry. It supports both mono and stereo inputs while always producing a mono output.
This device is suitable for guitars, musical instruments, laptops, mobile phones, and general audio sources.

### 2 Safety Information

- Operates from 230–240 V AC, 50 Hz. Do not open the enclosure while powered.
- Not battery powered.
- Reverse-polarity protection is internally provided.
- No user-serviceable parts inside.
- Use only standard audio cables and approved adapters.

### 3 Power Supply

The device contains an internal regulated dual-supply analog power system. Power is switched using the rear-panel rocker switch. Status LEDs indicate active modules only, not power faults.

### 4 Input and Output Connections

### 4.1 Audio Input

- Connector: 3.5 mm audio jack
- Mono or stereo input accepted
- Stereo inputs are internally summed to mono

### 4.2 Audio Output

- Connector: 3.5 mm audio jack
- Mono output signal
- Compatible with earphones, powered speakers, amplifiers, and audio interfaces

### 5 Front Panel Controls

### 5.1 Equalizer Section

- Volume: Master output level
- Bass: Low-frequency control
- Mid: Mid-frequency shaping
- Treble: High-frequency emphasis

### 5.2 Overdrive

- Toggle switch enables/disables distortion
- Depth knob controls clipping intensity
- LED indicates active overdrive

1

### 5.3 Tremolo

- Depth control sets modulation depth
- Rate control sets modulation speed
- LED indicates tremolo activity

### 5.4 Phaser

- Depth controls phase shift intensity
- Rate controls sweep frequency
- LED indicates active phaser

### 6 How to Use the Device

1. Connect the audio source to the input jack.
2. Connect earphones, speakers, or amplifier to the output.
3. Power on the device using the rear switch.
4. Enable desired effects using individual toggle switches.
5. Adjust knobs gradually to shape the sound.
6. Combine multiple effects as required.

### 7 Supported Audio Sources

- Electric and acoustic guitars
- Musical instruments with line output
- Laptop and mobile phone audio
- Recorded audio and general line-level signals

### 8 Handling and Maintenance

- Operate using hand controls only
- Avoid excessive heat and moisture
- Clean with a dry cloth
- Do not apply mechanical force to knobs or switches

### 9 Disclaimer

This device is an academic and experimental analog electronics project. Performance may vary depending on source impedance, load conditions, and external equipment.

Analog Audio Effect Processor
Made by Team Supertronics, University of Moratuwa, Sri Lanka

2

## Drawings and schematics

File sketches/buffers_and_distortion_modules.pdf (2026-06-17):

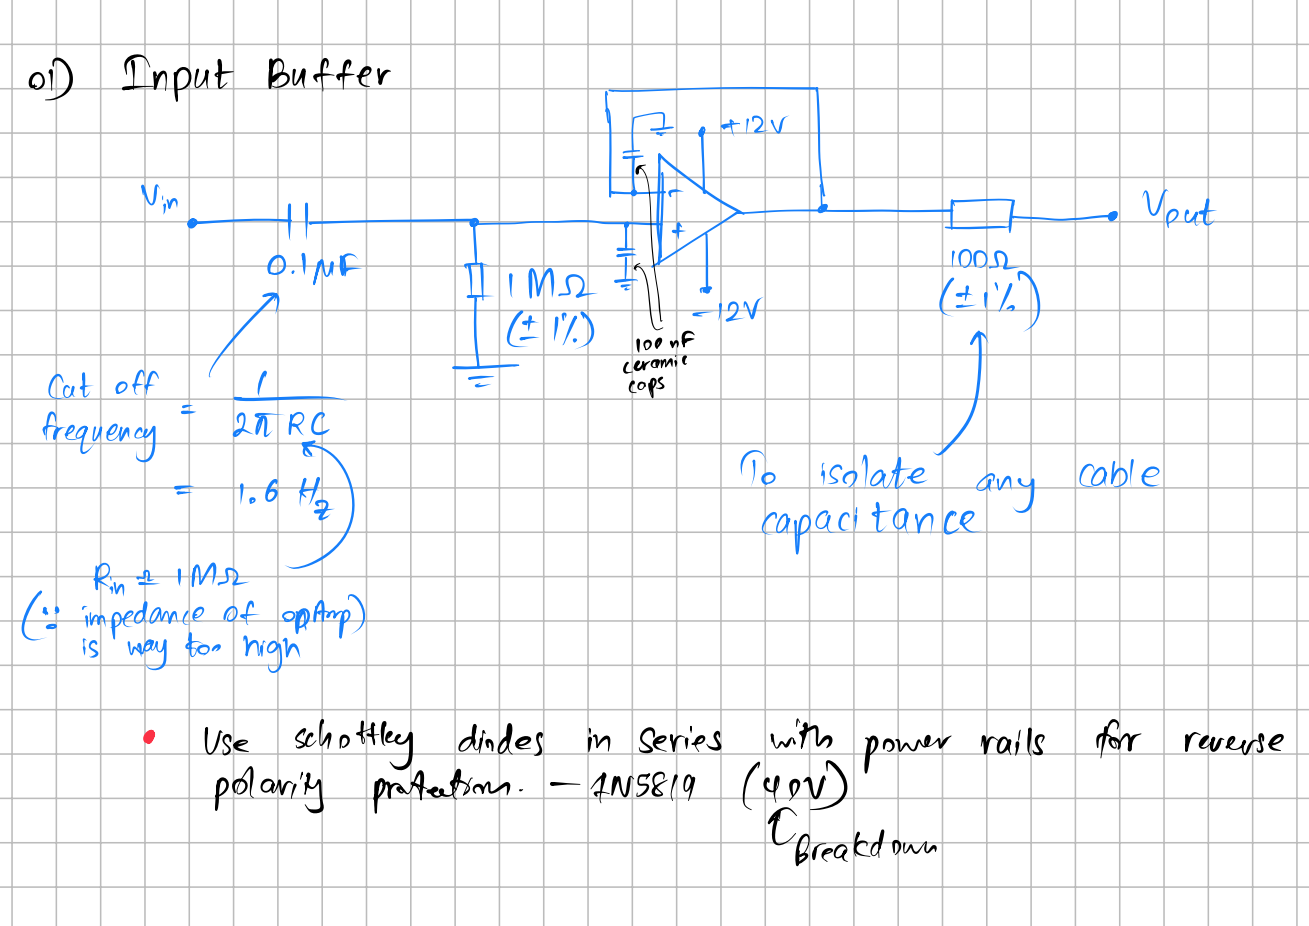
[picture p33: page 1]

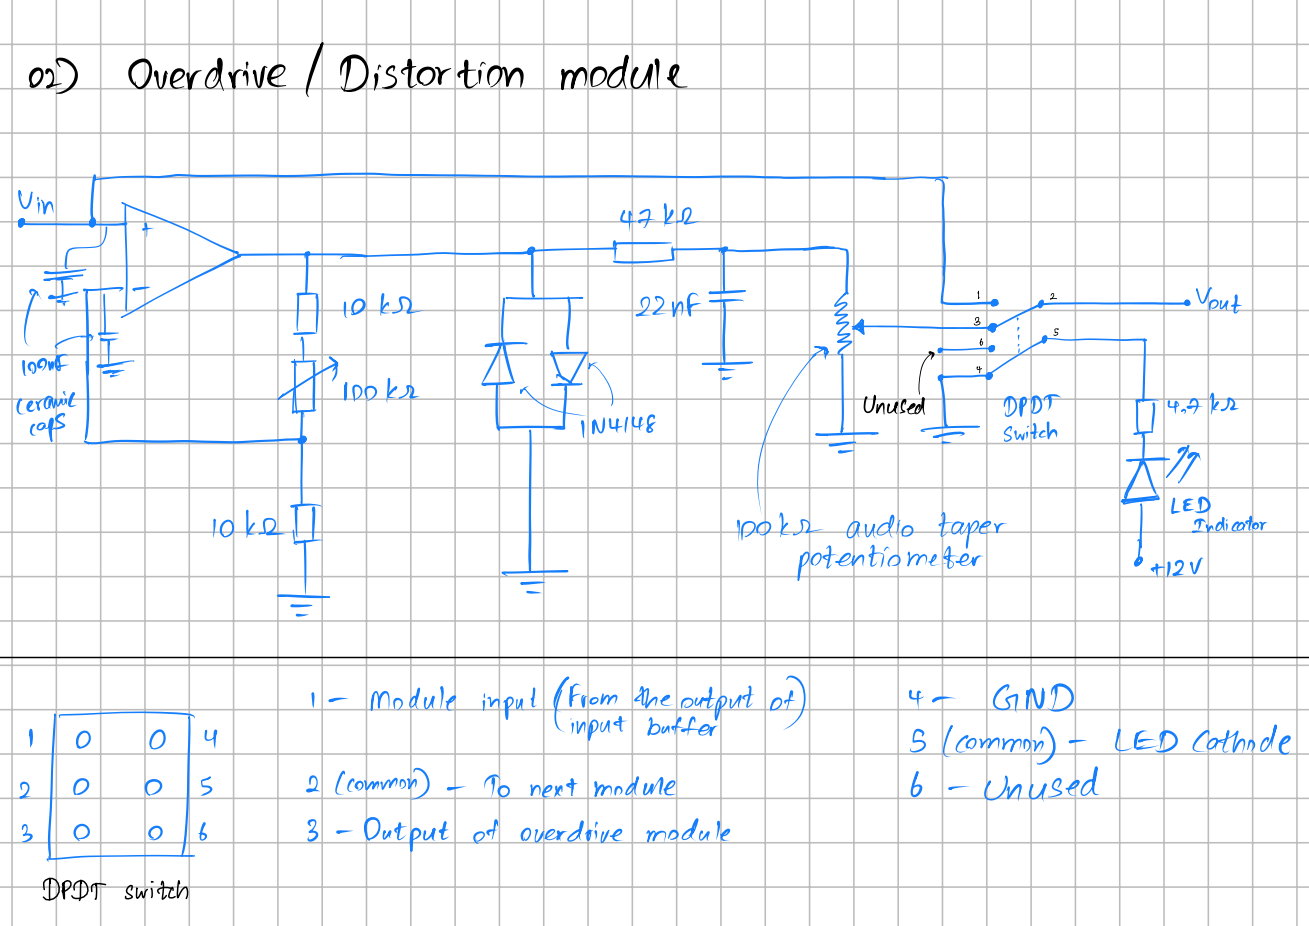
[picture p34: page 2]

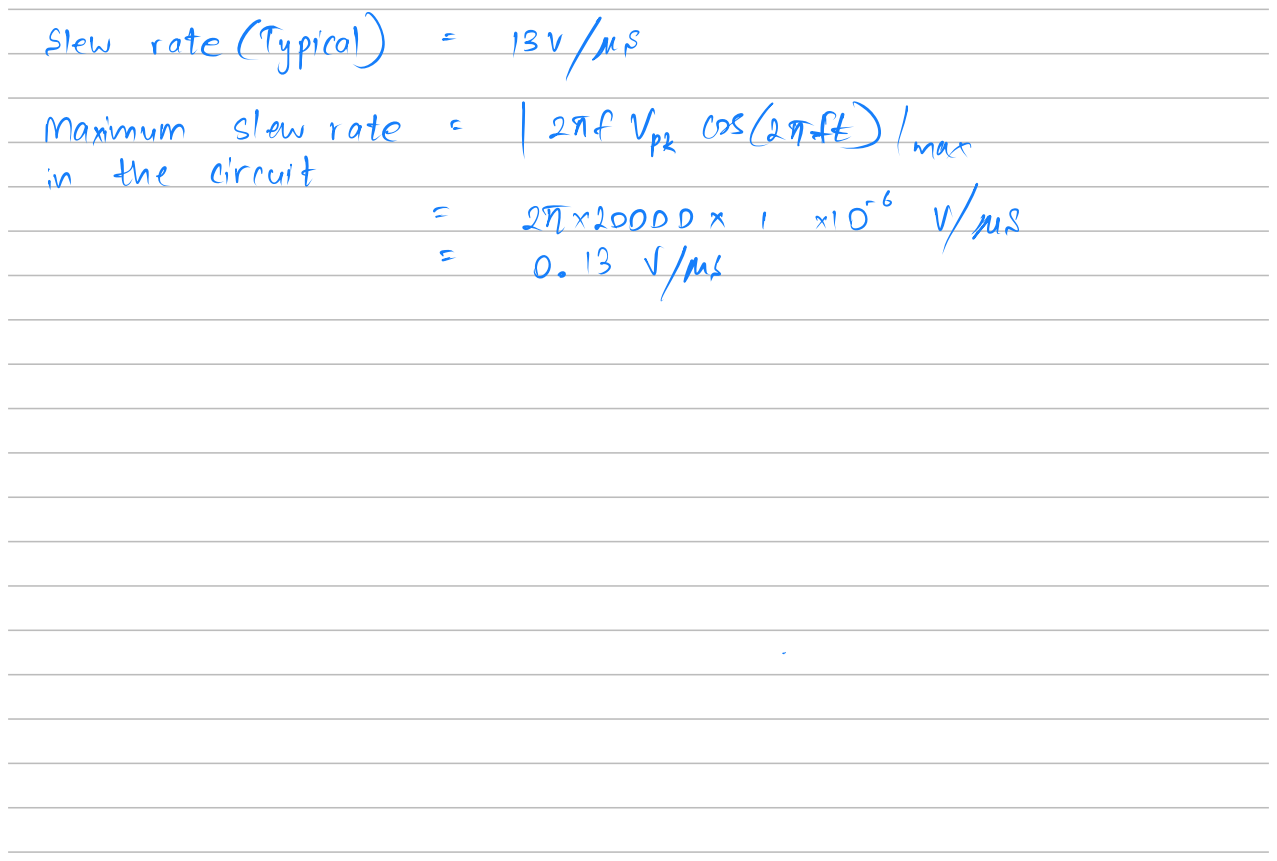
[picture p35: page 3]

🧩 Component Positions (Step by Step)
1⃣ Input Connection

On the left, a wire from the buffer output feeds this module.

Before entering the gain stage, you can place a small series resistor (~1 kΩ) to isolate any cable capacitance (optional).

2⃣ Op-Amp Gain Stage (Hard Clipping Driver)

Place one half of a TL072 op-amp in non-inverting configuration:

Non-inverting input (+) receives the input signal directly.

Inverting input (–) has:

Resistor Rg (10 kΩ) from (–) to ground.

Feedback resistor Rf (220 kΩ) from op-amp output back to (–).

Drive potentiometer: You can replace Rf with a 100 kΩ pot in series with 120 kΩ fixed resistor, so you can vary gain. Physically, draw the pot as a variable resistor symbol between output and (–).

Op-amp power pins go to ±12 V rails (top pin to +12 V, bottom to –12 V) with 0.1 µF decoupling capacitors to ground near the op-amp.

3⃣ Hard Clipping Diodes

From the op-amp output node, draw two 1N4148 diodes in opposite directions to ground:

One diode’s anode goes to output and cathode to ground.

The other diode’s cathode goes to output and anode to ground.

Position them vertically under the output trace, forming a “back-to-back” pair.

These will clip the waveform symmetrically at ≈±0.7 V → hard distortion.

4⃣ Tone Filter

After the diode junction (still on the output line), insert a passive low-pass RC network:

Series resistor (47 kΩ) in the output line.

After that resistor, branch a capacitor (22 nF) down to ground.

This forms a single-pole low-pass to tame harsh highs.

5⃣ Output Level Control

Place a 10 kΩ or 100 kΩ audio taper potentiometer after the tone filter:

The wiper (middle terminal) goes to the output.

One outer lug receives the filtered signal.

The other outer lug connects to ground.

This pot sets the final output level before the bypass switch.

6⃣ Bypass Switch (DPDT Toggle or Footswitch)

Draw a DPDT switch block after the level pot:

Top row: one throw connects the effect output to the chain output, the other throw connects input straight through (for bypass).

Bottom row: routes the LED control (or can route ground for true-bypass).

In effect ON position: buffer → op-amp → diodes → tone → level pot → output.

In bypass: input is directly connected to output, completely skipping the overdrive stage.

7⃣ Indicator LED

Use the other pole of the DPDT:

Connect +12 V through a current-limiting resistor (e.g., 4.7 kΩ) to the LED anode.

LED cathode goes to the switch, which either connects it to ground (ON) or leaves it floating (OFF).

Position the LED symbol near the switch on the front panel—this gives a clear “Overdrive Active” indication.

8⃣ Output Connection

After the bypass switch, draw a line to the next module input (e.g., phaser or tremolo).

## +------------------- 100Ω ---------------> Tip (Left) Mono signal ──┬───┤

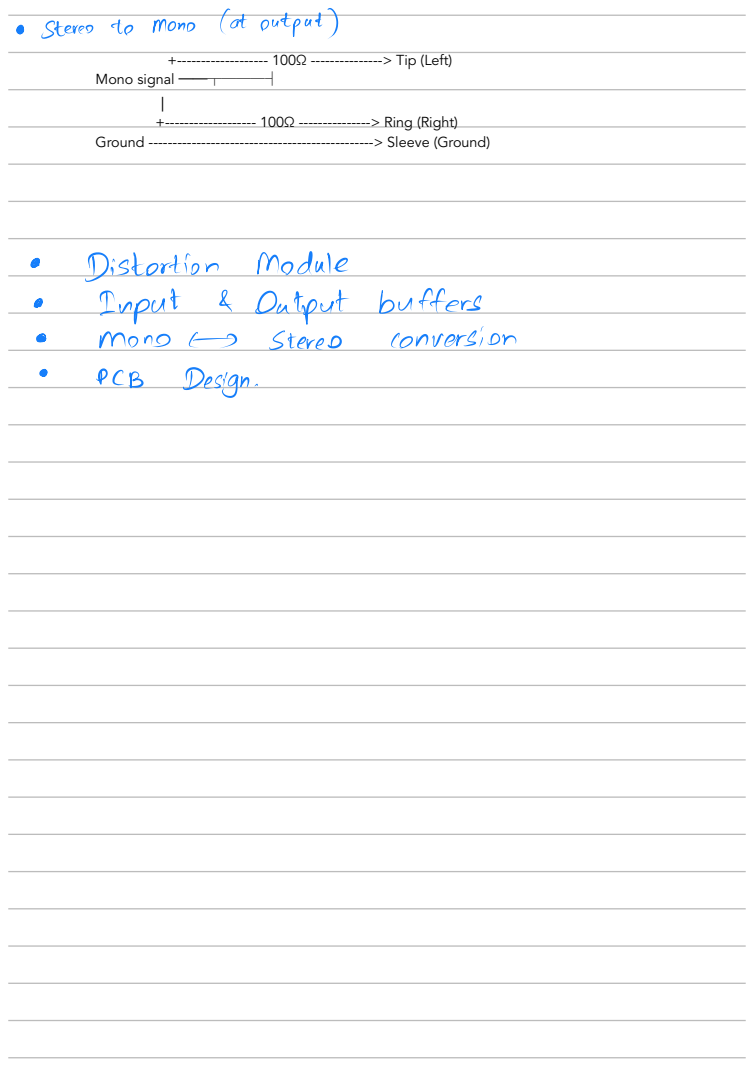
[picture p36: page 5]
│ +------------------- 100Ω ---------------> Ring (Right)

Ground -----------------------------------------------> Sleeve (Ground)
